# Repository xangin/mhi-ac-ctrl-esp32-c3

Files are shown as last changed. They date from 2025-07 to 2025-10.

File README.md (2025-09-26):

# mhi-ac-ctrl-esp32-c3
Control MHI Airconditioning locally by using ESP32C3 with ESPhome

This is a customized version of [hberntsen/mhi-ac-ctrl-esp32-c3](https://github.com/hberntsen/mhi-ac-ctrl-esp32-c3).

## 三菱重工冷氣ESPhome

這是使用ESP32C3搭配ESPhome來控制三菱重工冷氣的專案，可適用壁掛及吊隱式冷氣

感謝[hberntsen/mhi-ac-ctrl-esp32-c3](https://github.com/hberntsen/mhi-ac-ctrl-esp32-c3)開發ESPhome韌體，搭配我設計的[硬體](Hardware.md)，即可本地端控制三菱重工冷氣

適用型號: 支援外接原廠Wi-Fi智慧模組的機型，機器上有白色5pin的XH2.54mm底座就能使用



## 燒錄檔與ESPhome程式碼 Bin & YAML

YAML修改基本上只要修改最頂端的名稱即可，方便OTA與辨識是哪一台，也可將用不到的實體註解掉

| 檔名 | 適用機型 | 燒錄方式 | Bin檔 | YAML |
|---|:-----:|:-----:|:-----:|---|
| mhi-ac-wall.factory.bin | 壁掛式 | 接USB直接燒錄 | [Bin檔](mhi-ac-wall.factory.bin) | [YAML](mhi-ac-wall.yaml) |
| mhi-ac-wall.ota.bin | 壁掛式 | OTA用 | [Bin檔](mhi-ac-wall.ota.bin) | [YAML](mhi-ac-wall.yaml) |
| mhi-ac-ceiling.factory.bin | 吊隱式 | 接USB直接燒錄 | [Bin檔](mhi-ac-ceiling.factory.bin) | [YAML](mhi-ac-ceiling.yaml) |
| mhi-ac-ceiling.ota.bin | 吊隱式 | OTA | [Bin檔](mhi-ac-ceiling.ota.bin) | [YAML](mhi-ac-ceiling.yaml) |

## 如何下載

點擊檔案名稱>點右上角有個下載的圖案(Download Raw file)>儲存

## Bin檔使用方法

### A. 透過USB

1. 下載名稱結尾是factory.bin的檔案至電腦
2. 模組透過usb接上電腦
3. 用chrome或edge瀏覽器前往 [https://web.esphome.io](https://web.esphome.io/)
4. 按Connect>選擇寫USB JTAG>按INSTALL>選擇剛儲存的Bin檔，等待燒錄完成
5. 顯示finish後，就可看到ESP32上面的藍燈開始閃爍，這時候等待久一點，會看到有熱點跑出來
6. 點連線並輸入Wi-Fi密碼: 12345678
7. 連上後輸入http://192.168.4.1
8. 進到網頁選擇家中Wi-Fi名稱及輸入密碼後按儲存，連上後HA應該就會自動發現此裝置

### B. OTA

1. 下載名稱結尾是ota.bin的檔案至電腦
2. 在瀏覽器網址列輸入裝置IP
3. 最下方OTA Update選擇ota.bin檔>按Update，等待畫面跳轉為done即完成

## 硬體架構

詳細請參考[Hardware.md](Hardware.md)

## 致謝 Credit & Thanks

Based on the excellent work of [hberntsen/mhi-ac-ctrl-esp32-c3](https://github.com/hberntsen/mhi-ac-ctrl-esp32-c3), and thanks to hberntsen for his contributions to the ESPHome community.
Licensed under MIT.

感謝協助測試硬體的RyanChu、KIMI、HsuHank，設計3D外殼的紅軍

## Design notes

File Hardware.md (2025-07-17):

# 硬體設計 Hardware

## 電路圖 Schematic
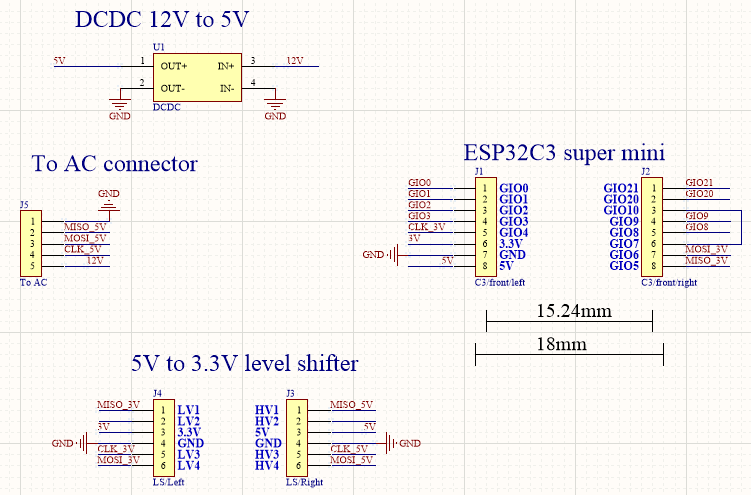
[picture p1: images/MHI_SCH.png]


### 設計說明

1. GPIO10要與任一GPIO對接，此設計是接GPIO7

2. level shifter僅用3個，1個用不到

3. 連接至冷氣的此設計用90度彎針，也能直接用180度母頭，但焊接時需注意接頭方向，焊反插上去會燒，方向可參考下面冷氣底座

### Design Notes

1. GPIO10 must be connected to any other GPIO pin. In this design, it is connected to GPIO7.

2. Only three level shifters are used; one is left unused.

3. The connection to the air conditioner in this design uses a 90-degree pin header. A straight (180-degree) female header can also be used, but you must pay close attention to the orientation during soldering. Soldering it in the wrong direction will cause it to burn out when plugged in. You can refer to the air conditioner's base below for the correct orientation.

## 電路板 PCB

Size: 46.5mm x 26mm

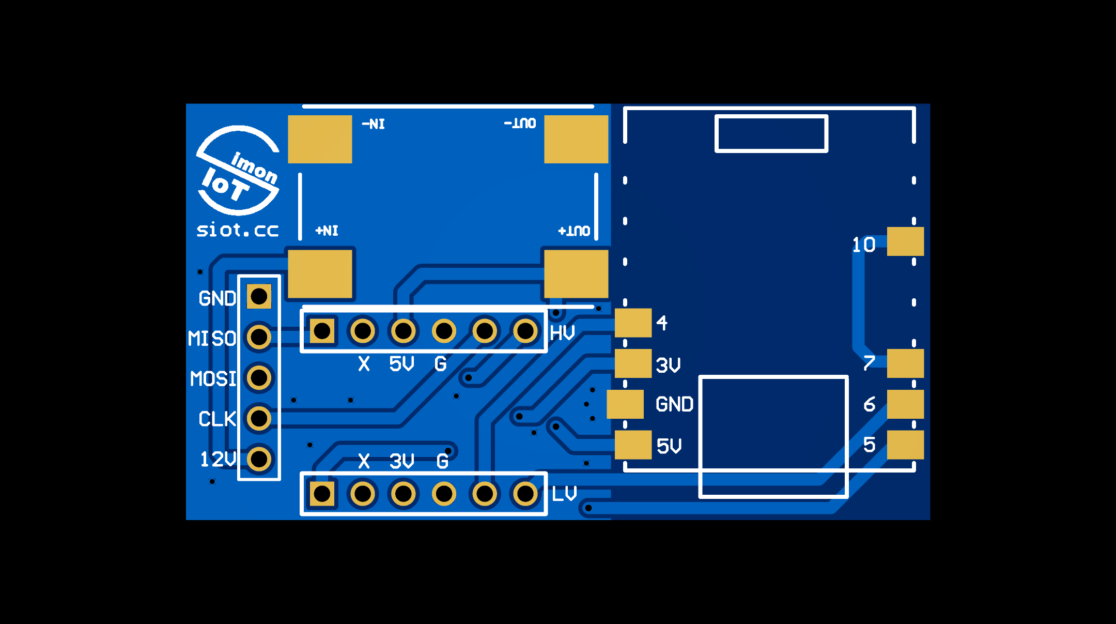
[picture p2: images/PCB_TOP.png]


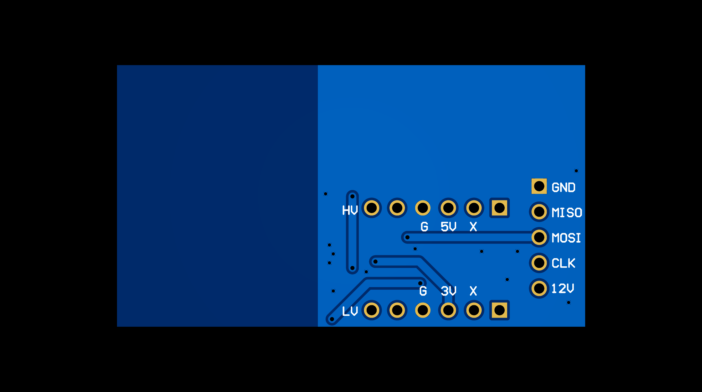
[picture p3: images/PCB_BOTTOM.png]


## 成品圖 Finished Product

1. 焊接完成的板子: **要剃除模組上的天線，收訊才會好!!**

Soldered Board: The SMD antenna on the module **MUST be removed** to ensure good reception!

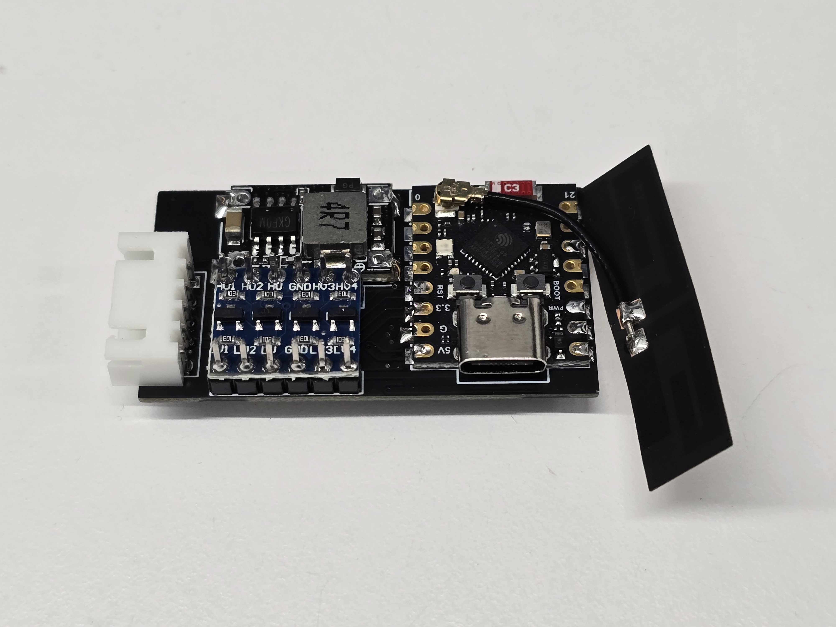
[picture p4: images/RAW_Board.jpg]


2. 放入3D列印殼中:

Placed in 3D-Printed Case:

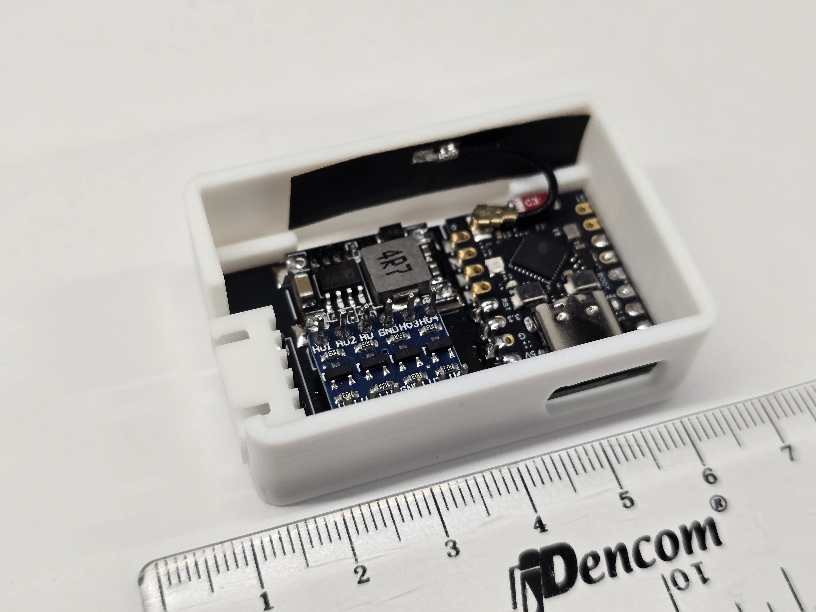
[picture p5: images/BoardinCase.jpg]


3. 完成品，蓋上蓋與接上排線:

Final Assembly: Case closed and cable connected.

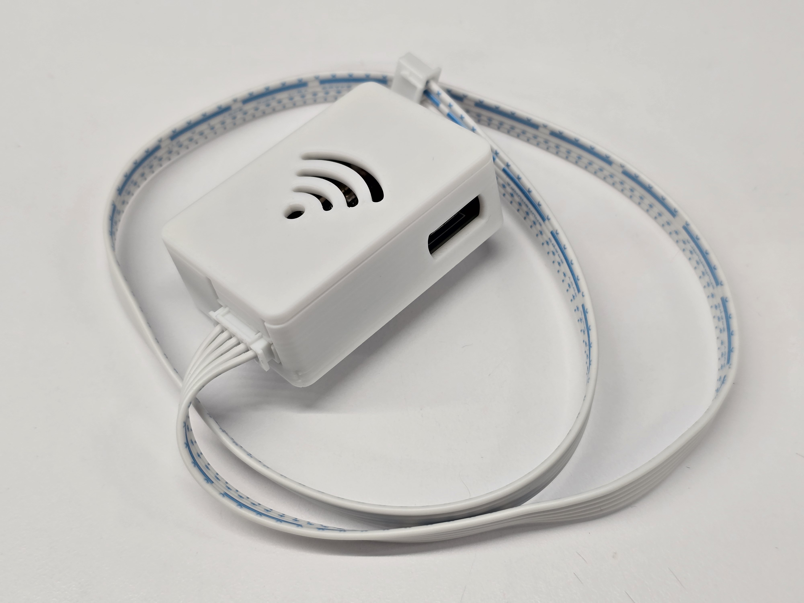
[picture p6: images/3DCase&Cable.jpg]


## 材料清單 Bill of Material

1. ESP32C3 super mini
2. 37*10mm FPC antenna 3cm long
3. DCDC 12V to 5V
4. 5V to 3.3V 4channel level shifter
5. XH2.54mm-5p 90degree male
6. XH2.54mm-5p female to female cable 50cm long

## 冷氣底座腳位定義 AC connector pin definition



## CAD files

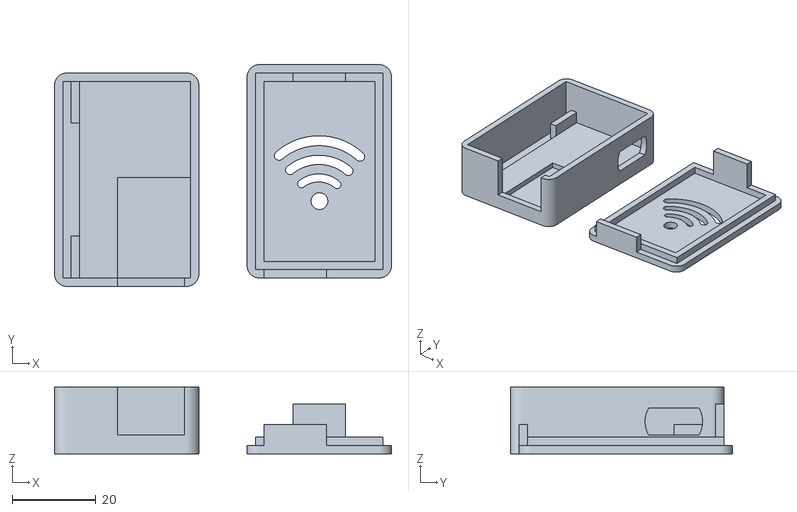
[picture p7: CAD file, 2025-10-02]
mhi-case-hole.stl
80.5 x 53.0 x 16.0

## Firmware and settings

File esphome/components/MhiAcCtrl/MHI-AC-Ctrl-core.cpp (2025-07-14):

// MHI-AC-Ctrol-core
// implements the core functions (read & write SPI)

#include "MHI-AC-Ctrl-core.h"

#include <math.h>
#include <string.h>
#include <algorithm>
#include <ranges>

#include "driver/gptimer.h"
#include "driver/spi_slave.h"
#include "driver/gpio.h"

#include "esp_log.h"

#include "MHI-AC-CTRL-operation-data.h"
static const char *TAG = "MHI-AC-CTRL-core";

using namespace mhi_ac;
using namespace mhi_ac::internal;


#define vTaskDelayMs(ms)            vTaskDelay((ms)/portTICK_PERIOD_MS)

#define ESP_INTR_FLAG_DEFAULT       0                                           // default to allocating a non-shared interrupt of level 1, 2 or 3.

gptimer_handle_t cs_timer = NULL;
static TaskHandle_t mhi_poll_task_handle = NULL;

static bool active_mode = false;
static gpio_num_t gpio_cs_out;

static DMA_ATTR std::array<uint8_t, MHI_FRAME_LEN_LONG> sendbuf;
static DMA_ATTR std::array<uint8_t, MHI_FRAME_LEN_LONG> recvbuf;
static DMA_ATTR std::array<uint8_t, MHI_FRAME_LEN_LONG> recvbuf2;

static uint32_t frame_errors = 0;

namespace mhi_ac {
Energy energy(230);
SpiState spi_state;
operation_data::State operation_data_state;

static void IRAM_ATTR gpio_isr_handler(void* arg)
{
  uint64_t current_timer_value;
  // We need to know whether the timer has already been started. If we start it when it is already started, we get the
  // following in the logs:
  // > gptimer: gptimer_start(348): timer is not enabled in the logs
  //
  // There is no direct API to check the status, so use the raw count instead
  ESP_ERROR_CHECK(gptimer_get_raw_count(cs_timer, &current_timer_value));
  if(current_timer_value == 0) {
    gptimer_start(cs_timer);
  } else {
    ESP_ERROR_CHECK(gptimer_set_raw_count(cs_timer, 0));
  }
}

static bool IRAM_ATTR gptimer_isr_callback(gptimer_handle_t timer, const gptimer_alarm_event_data_t *edata, void *user_ctx)
{
    BaseType_t xHigherPriorityTaskWoken = pdFALSE;

    // Stop timer, gpio isr will turn it back on
    gptimer_stop(timer);
    // Set to 0 to tell the GPIO isr that the timer is not running
    gptimer_set_raw_count(cs_timer, 0);

    // Trigger Chip Select low->high->low
    gpio_set_level(gpio_cs_out, 1);
    gpio_set_level(gpio_cs_out, 0);

    vTaskNotifyGiveFromISR(mhi_poll_task_handle, &xHigherPriorityTaskWoken);

    return xHigherPriorityTaskWoken;
}

bool SpiState::snapshot_semaphore_take() {
  return xSemaphoreTake(this->snapshot_semaphore_handle_, 0) == pdTRUE;
}

void SpiState::snapshot_semaphore_give() {
  xSemaphoreGive(this->snapshot_semaphore_handle_);
}

void SpiState::set_snapshot_as_previous() {
  this->mosi_frame_snapshot_prev_ = this->mosi_frame_snapshot_;
}

static bool validate_signature(uint8_t sb0, uint8_t sb1, uint8_t sb2) {
  return (sb0 & 0xfe) == 0x6c && sb1 == 0x80 && sb2 == 0x04;
}

bool SpiState::has_received_data() {
  return validate_signature(this->mosi_frame_snapshot_[SB0], this->mosi_frame_snapshot_[SB1], this->mosi_frame_snapshot_[SB2]);
}

void SpiState::use_long_frame(bool long_frame_enabled) {
  xSemaphoreTake(this->miso_semaphore_handle_, portMAX_DELAY);
  this->miso_frame_[SB0] = long_frame_enabled ? 0xAA : 0xA9;
  xSemaphoreGive(this->miso_semaphore_handle_);
}

void active_mode_set(bool state) {
    active_mode = state;
    if(!active_mode) {
        // Ensure we stop counting power when active mode is off
        energy.set_current(0);
    }
}

bool active_mode_get() {
    return active_mode;
}

#define CLAMP(x, lower, upper) (MIN(upper, MAX(x, lower)))

void SpiState::target_temperature_set(float target_temperature) {
  xSemaphoreTake(this->miso_semaphore_handle_, portMAX_DELAY);
  uint8_t tsetpoint = (uint8_t)roundf(CLAMP(target_temperature*2, 0.f*2, 30.f*2));
  this->miso_frame_[DB2] = tsetpoint;
  this->miso_frame_[DB2] |= 1 << 7;      // set bit for temp
  ESP_LOGD(TAG, "Set temperature, new DB2: %x (from source temp %f)", this->miso_frame_[DB2], target_temperature);
  xSemaphoreGive(this->miso_semaphore_handle_);
}

bool SpiState::target_temperature_changed() const {
  return (this->mosi_frame_snapshot_[DB2] &~ (1 << 7)) != (this->mosi_frame_snapshot_prev_[DB2] &~ (1 << 7));
}

float SpiState::target_temperature_get() const {
  float temp = this->mosi_frame_snapshot_[DB2] &~ (1 << 7);
  return temp / 2.0f;
}

bool SpiState::power_changed() const {
  return (this->mosi_frame_snapshot_[DB0] & PWR_MASK) != (this->mosi_frame_snapshot_prev_[DB0] & PWR_MASK);
}

void SpiState::power_set(ACPower power) {
  xSemaphoreTake(this->miso_semaphore_handle_, portMAX_DELAY);
  this->miso_frame_[DB0] &= ~PWR_MASK;                       // clear what is there first
  this->miso_frame_[DB0] |= (uint8_t)power;                  // set the setting
  this->miso_frame_[DB0] |= 1 << 1;                          // DB0[1] 'set setting bit'
  xSemaphoreGive(this->miso_semaphore_handle_);
}

ACPower SpiState::power_get() const {
  if(this->mosi_frame_snapshot_[DB0] & PWR_MASK)
    return ACPower::power_on;
  else
    return ACPower::power_off;
}

bool SpiState::mode_changed() const {
  return (this->mosi_frame_snapshot_[DB0] & MODE_MASK) != (this->mosi_frame_snapshot_prev_[DB0] & MODE_MASK);
}

void SpiState::mode_set(ACMode mode) {
  if(mode == ACMode::mode_unknown) {
    return;
  }
  xSemaphoreTake(this->miso_semaphore_handle_, portMAX_DELAY);
  this->miso_frame_[DB0] &= ~MODE_MASK;                      // clear what is there first
  this->miso_frame_[DB0] |= (uint8_t)mode;                   // set the setting
  this->miso_frame_[DB0] |= 1 << 5;                          // 'set setting bit for mode'
  xSemaphoreGive(this->miso_semaphore_handle_);
}

ACMode SpiState::mode_get() const {
  uint8_t current_mode = this->mosi_frame_snapshot_[DB0] & MODE_MASK;
  switch(current_mode) {
    case (uint8_t)ACMode::mode_auto:
    case (uint8_t)ACMode::mode_dry:
    case (uint8_t)ACMode::mode_cool:
    case (uint8_t)ACMode::mode_fan:
    case (uint8_t)ACMode::mode_heat:
      return (ACMode) current_mode;
    default:
      return ACMode::mode_unknown;
  }
}

bool SpiState::fan_changed() const {
  return (this->mosi_frame_snapshot_[DB1] & FAN_MASK) != (this->mosi_frame_snapshot_prev_[DB1] & FAN_MASK);
}
void SpiState::fan_set(ACFan fan) {
  xSemaphoreTake(this->miso_semaphore_handle_, portMAX_DELAY);
  this->miso_frame_[DB1] &= ~FAN_MASK;
  this->miso_frame_[DB1] |= (uint8_t) fan;
  this->miso_frame_[DB1] |= 1 << 3;              // set bit for fan speed on DB1
  xSemaphoreGive(this->miso_semaphore_handle_);
}

ACFan SpiState::fan_get() const {
  uint8_t fan_value = this->mosi_frame_snapshot_[DB1] & FAN_MASK;
  switch(fan_value) {
    case (uint8_t) ACFan::speed_1:
    case (uint8_t) ACFan::speed_2:
    case (uint8_t) ACFan::speed_3:
    case (uint8_t) ACFan::speed_4:
    case (uint8_t) ACFan::speed_auto:
      return (ACFan) fan_value;
    default:
      return ACFan::unknown;
  }
}

bool SpiState::current_temperature_changed() const {
  return this->mosi_frame_snapshot_[DB3] != this->mosi_frame_snapshot_prev_[DB3];
}
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

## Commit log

2025-07-14 add schmetic by using ESP32C3 super mini
2025-07-14 Create mhi-ac-ceiling.yaml
    for MHI Ducted(Ceiling concealed) AC
2025-07-16 Update mhi-ac-ceiling.yaml
    switch back to the original author’s external_component
2025-07-16 Update mhi-ac-wall.yaml
    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
